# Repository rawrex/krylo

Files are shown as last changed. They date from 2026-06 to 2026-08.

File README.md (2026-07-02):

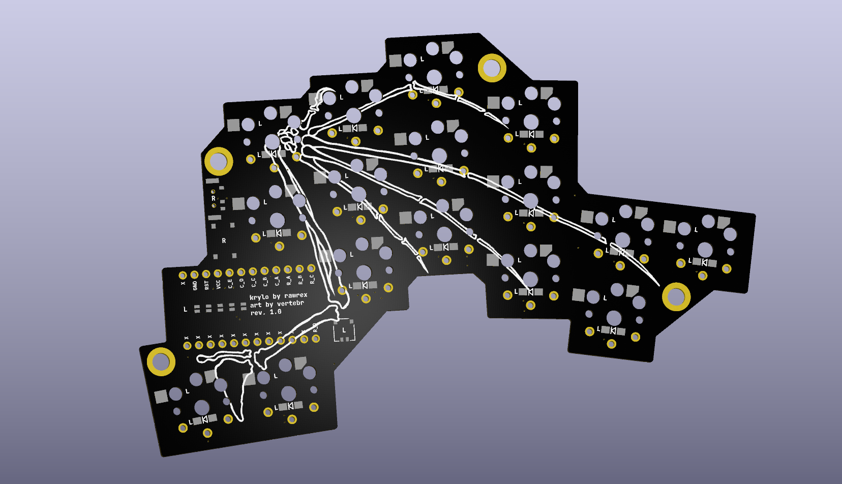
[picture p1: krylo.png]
krylo split keyboard


**Krylo** (*"wing"* in Russian) is a 32 key column-staggered split keyboard running [ZMK](https://zmk.dev/)

Core ideas that motivated the project:
- (My) pinky moves to the side better than it reaches forward to the upper row.
- (My) index finger is also able to move to the side, but it is not comfortable to move to the side and down.
- Single PCB symmetrical definition for both sides of the split.

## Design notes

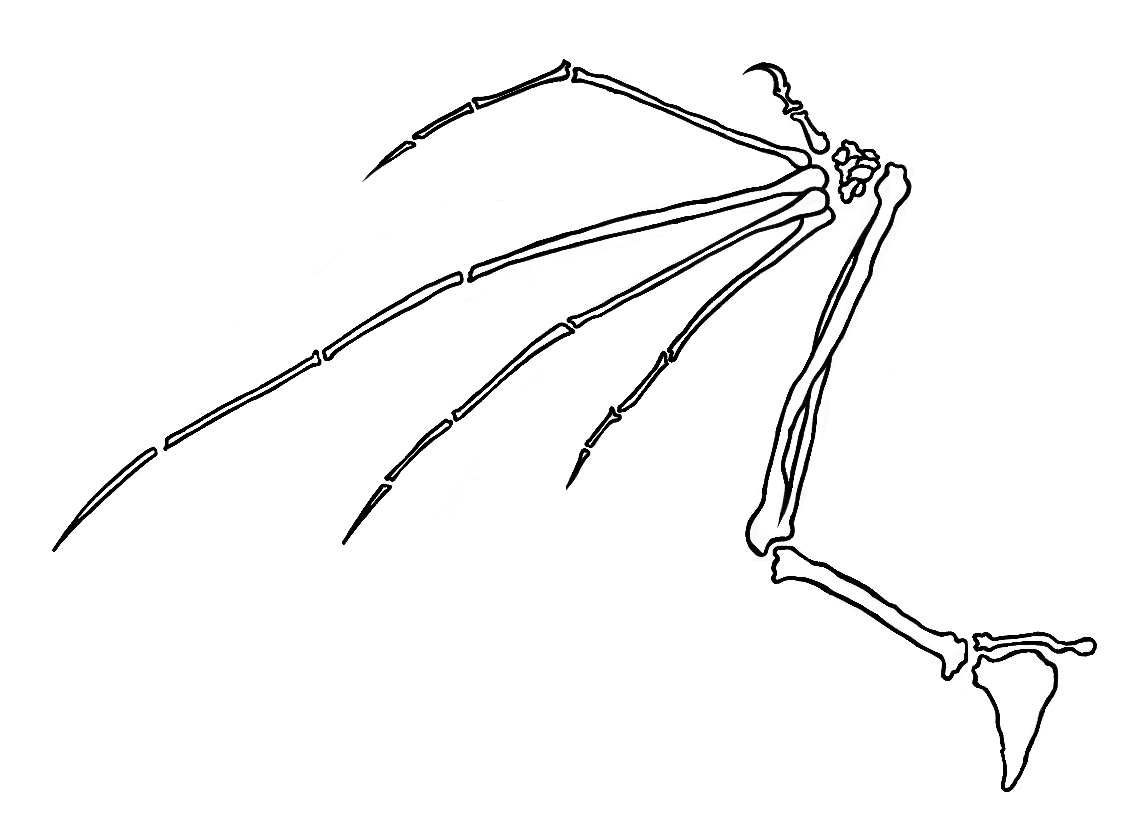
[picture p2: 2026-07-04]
PCB/krylo.png

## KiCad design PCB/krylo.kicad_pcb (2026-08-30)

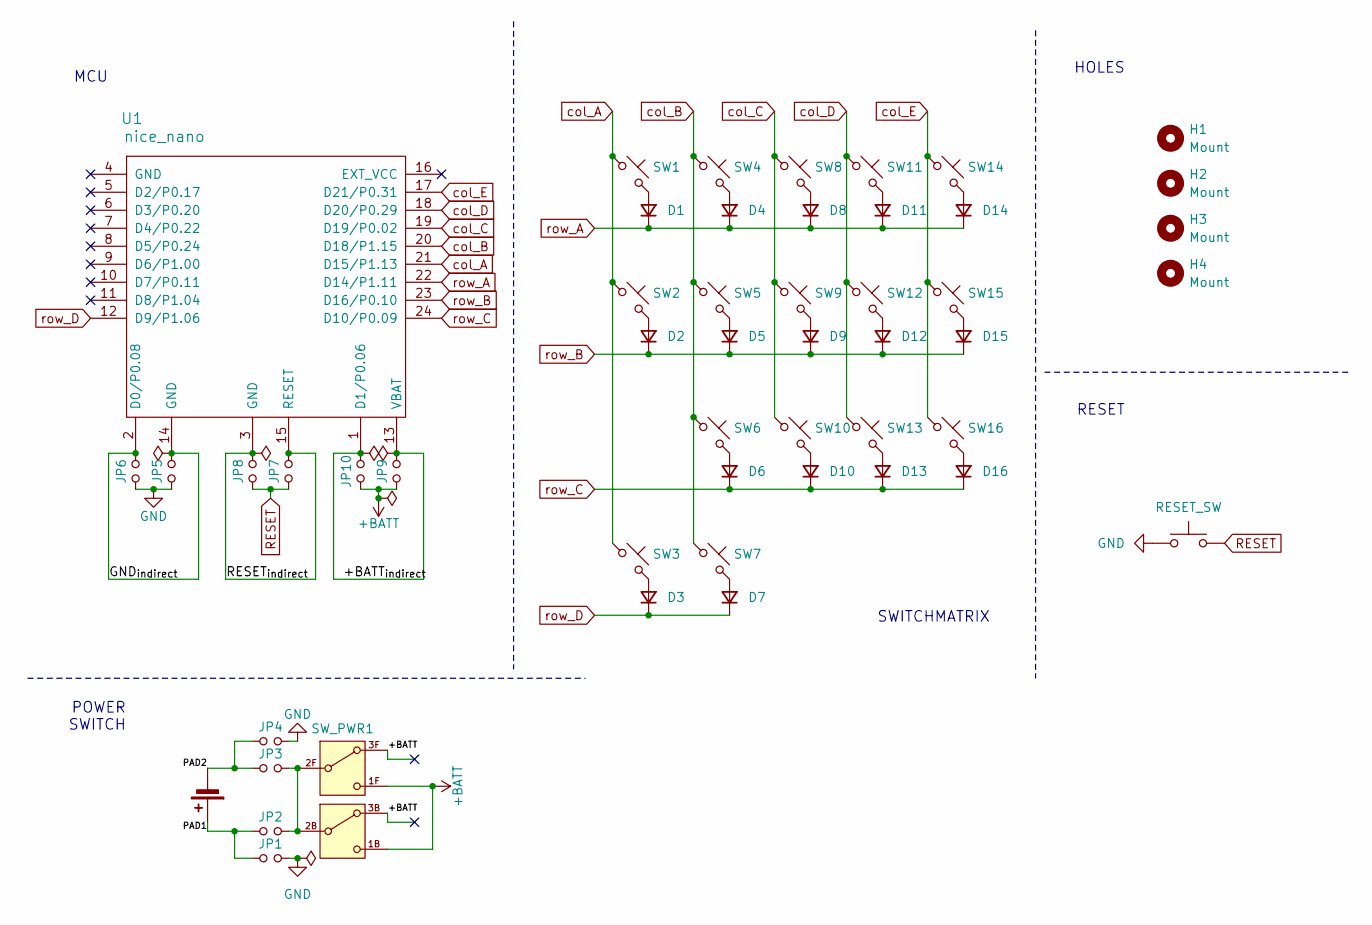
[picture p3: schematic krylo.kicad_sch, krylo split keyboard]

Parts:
BT1: MOLEX_C
D1, D2, D3, D4, D5, D6, D7, D8, D9, D10, D11, D12, D13, D14, D15, D16: D_SOD123
H1, H2, H3, H4: Mount
JP1, JP2, JP3, JP4, JP5, JP6, JP7, JP8, JP9, JP10: Jumper
RESET1: RESET_SW; ResetSW
SW1, SW2, SW3, SW4, SW5, SW6, SW7, SW8, SW9, SW10, SW11, SW12, SW13, SW14, SW15, SW16: Switch
SW_PWR1: MSK12C02
U1: nice_nano

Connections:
+BATT: JP9.1, JP10.1, SW_PWR1.1B (C_back), SW_PWR1.1F (C_front), SW_PWR1.3B (A_back), SW_PWR1.3F (A_front)
/+BATT_{indirect}: JP9.2, JP10.2, U1.1 (D1/P0.06), U1.13 (VBAT)
/GND_{indirect}: JP5.2, JP6.2, U1.2 (D0/P0.08), U1.14 (GND)
/PAD1: BT1.1 (+), JP1.1, JP2.1
/PAD2: BT1.2 (-), JP3.1, JP4.1
/RESET_{indirect}: JP7.2, JP8.2, U1.3 (GND), U1.15 (RESET)
GND: JP1.2, JP4.2, JP5.1, JP6.1, RESET1.1
unnamed: D1.2 (A), SW1.2
unnamed: D2.2 (A), SW2.2
unnamed: D3.2 (A), SW3.2
unnamed: D4.2 (A), SW4.2
unnamed: D5.2 (A), SW5.2
unnamed: D6.2 (A), SW6.2
unnamed: D7.2 (A), SW7.2
unnamed: D8.2 (A), SW8.2
unnamed: D9.2 (A), SW9.2
unnamed: D10.2 (A), SW10.2
unnamed: D11.2 (A), SW11.2
unnamed: D12.2 (A), SW12.2
unnamed: D13.2 (A), SW13.2
unnamed: D14.2 (A), SW14.2
unnamed: D15.2 (A), SW15.2
unnamed: D16.2 (A), SW16.2
unnamed: JP2.2, JP3.2, SW_PWR1.2B (B_back), SW_PWR1.2F (B_front)
RESET: JP7.1, JP8.1, RESET1.2
col_A: SW1.1, SW2.1, SW3.1, U1.21 (D15/P1.13)
col_B: SW4.1, SW5.1, SW6.1, SW7.1, U1.20 (D18/P1.15)
col_C: SW8.1, SW9.1, SW10.1, U1.19 (D19/P0.02)
col_D: SW11.1, SW12.1, SW13.1, U1.18 (D20/P0.29)
col_E: SW14.1, SW15.1, SW16.1, U1.17 (D21/P0.31)
row_A: D1.1 (K), D4.1 (K), D8.1 (K), D11.1 (K), D14.1 (K), U1.22 (D14/P1.11)
row_B: D2.1 (K), D5.1 (K), D9.1 (K), D12.1 (K), D15.1 (K), U1.23 (D16/P0.10)
row_C: D6.1 (K), D10.1 (K), D13.1 (K), D16.1 (K), U1.24 (D10/P0.09)
row_D: D3.1 (K), D7.1 (K), U1.12 (D9/P1.06)

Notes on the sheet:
SWITCHMATRIX
POWER SWITCH
HOLES
MCU
RESET

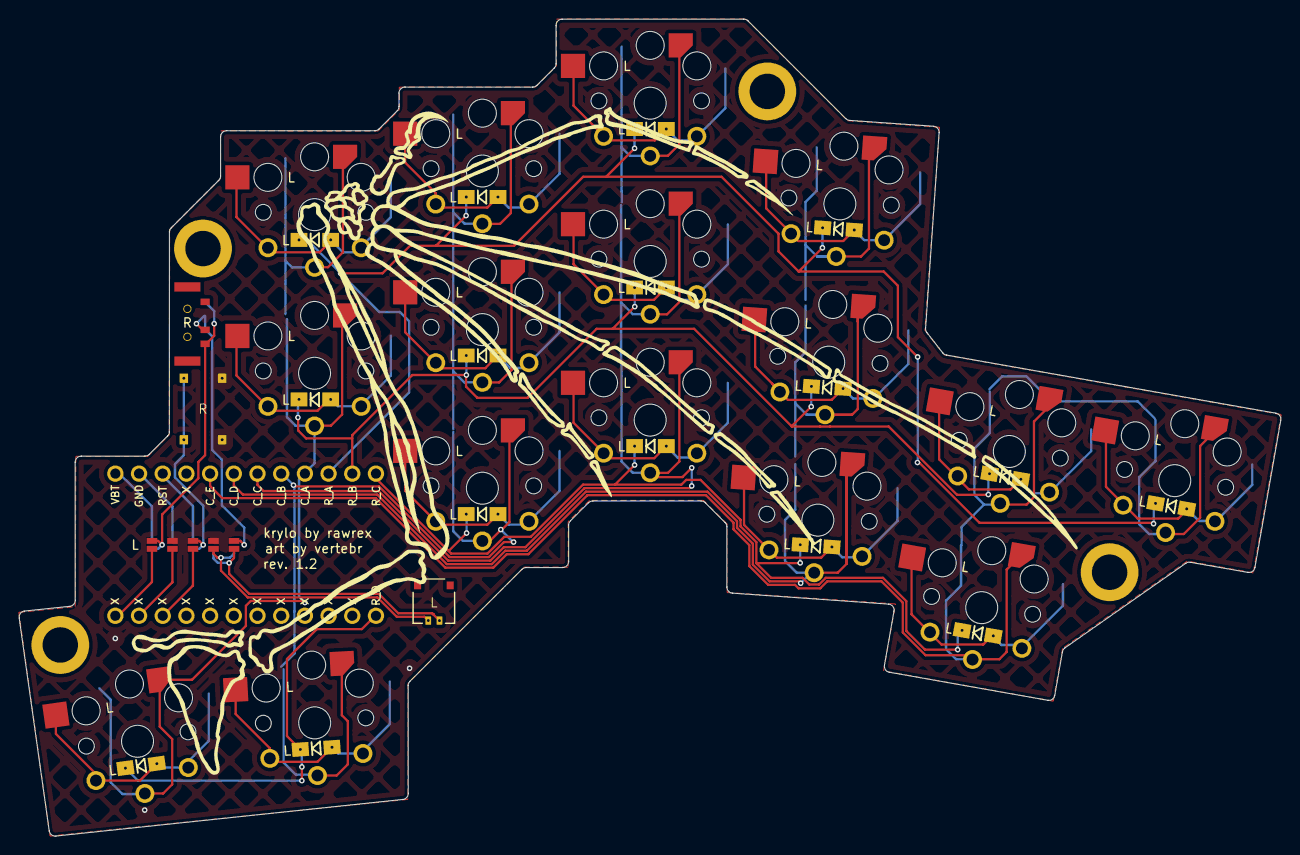
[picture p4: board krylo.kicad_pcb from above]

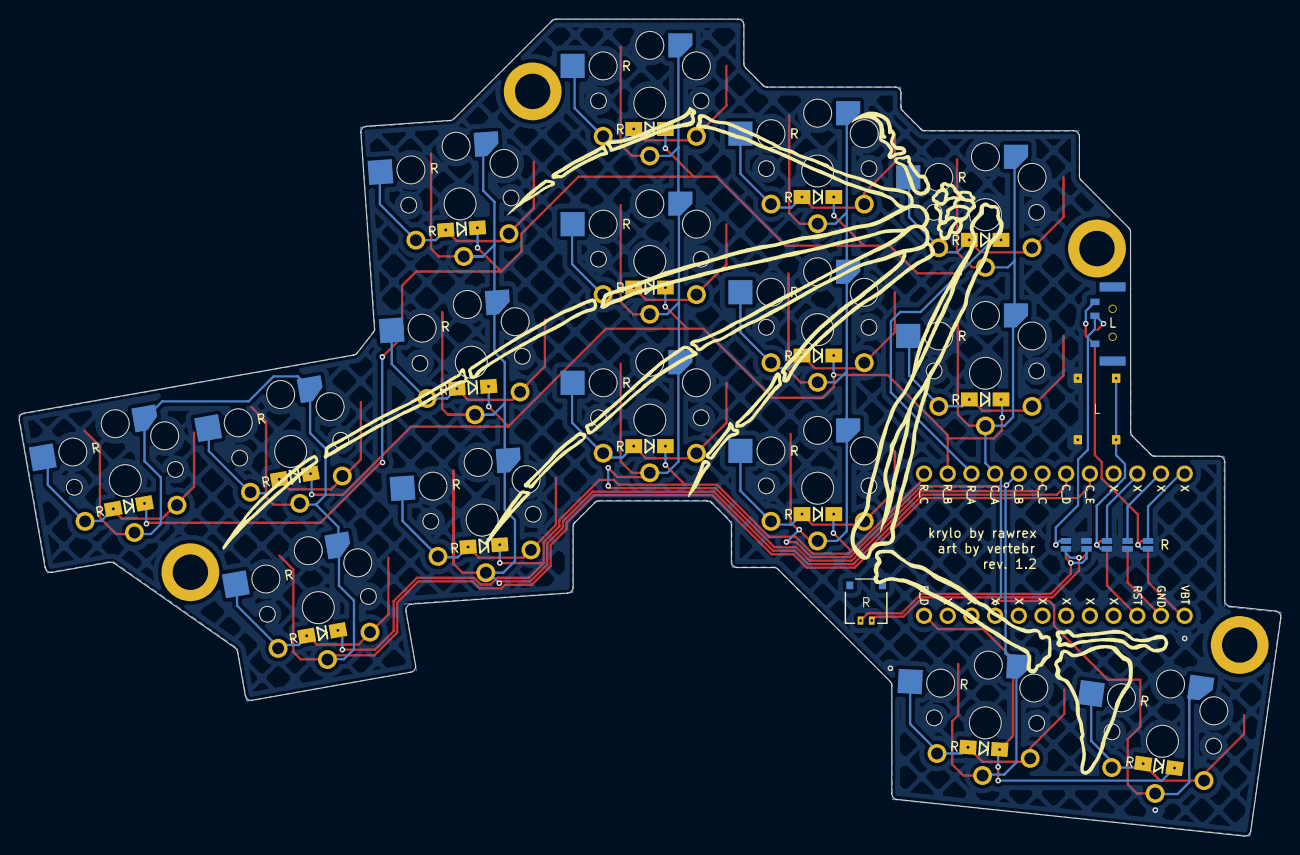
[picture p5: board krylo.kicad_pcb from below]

Board: 2 copper layers, 135.3 x 87.6 mm, 51 parts (5 on the bottom side), 34 nets.

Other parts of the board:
INFO: Info

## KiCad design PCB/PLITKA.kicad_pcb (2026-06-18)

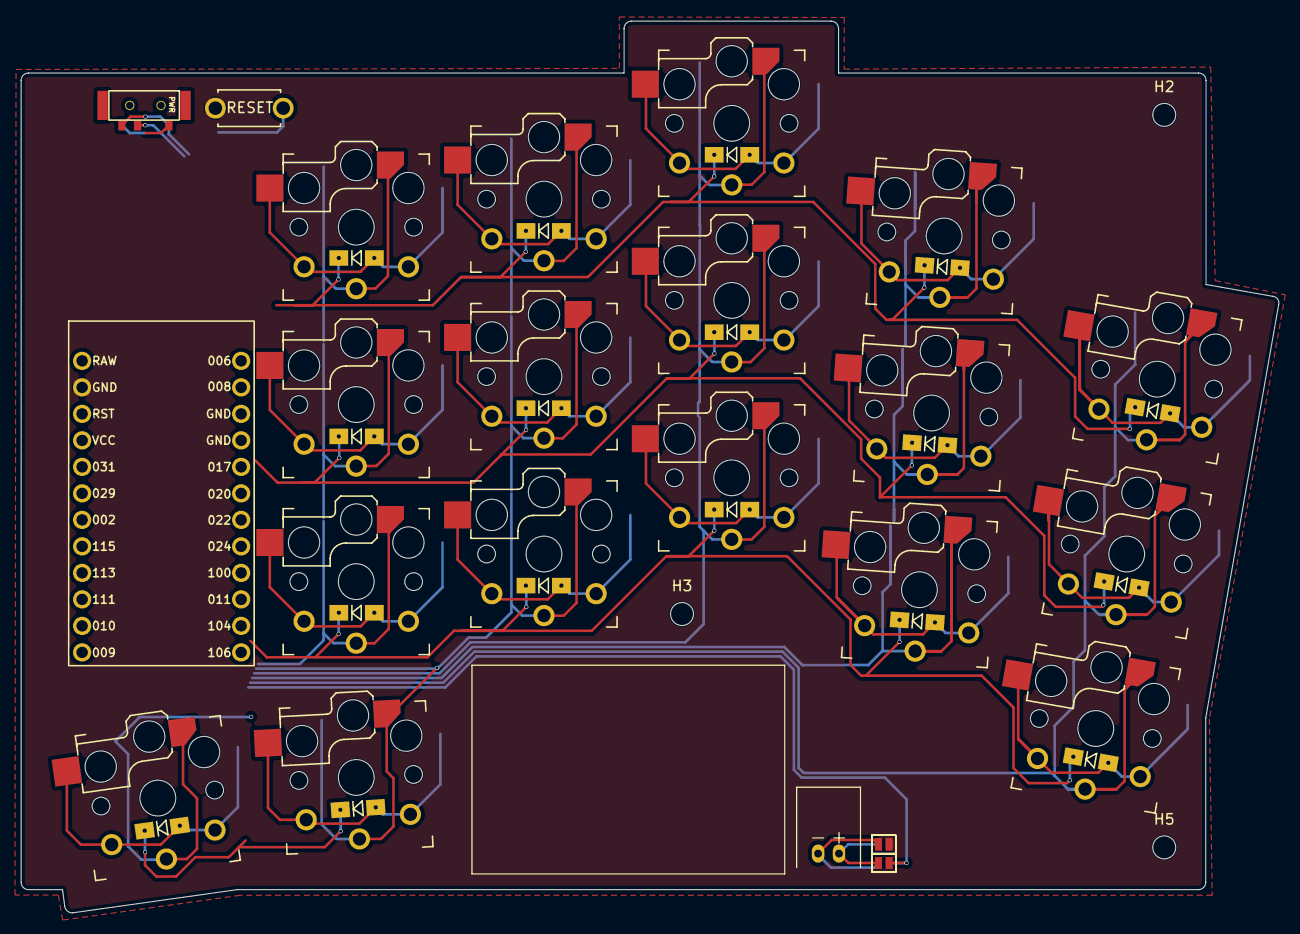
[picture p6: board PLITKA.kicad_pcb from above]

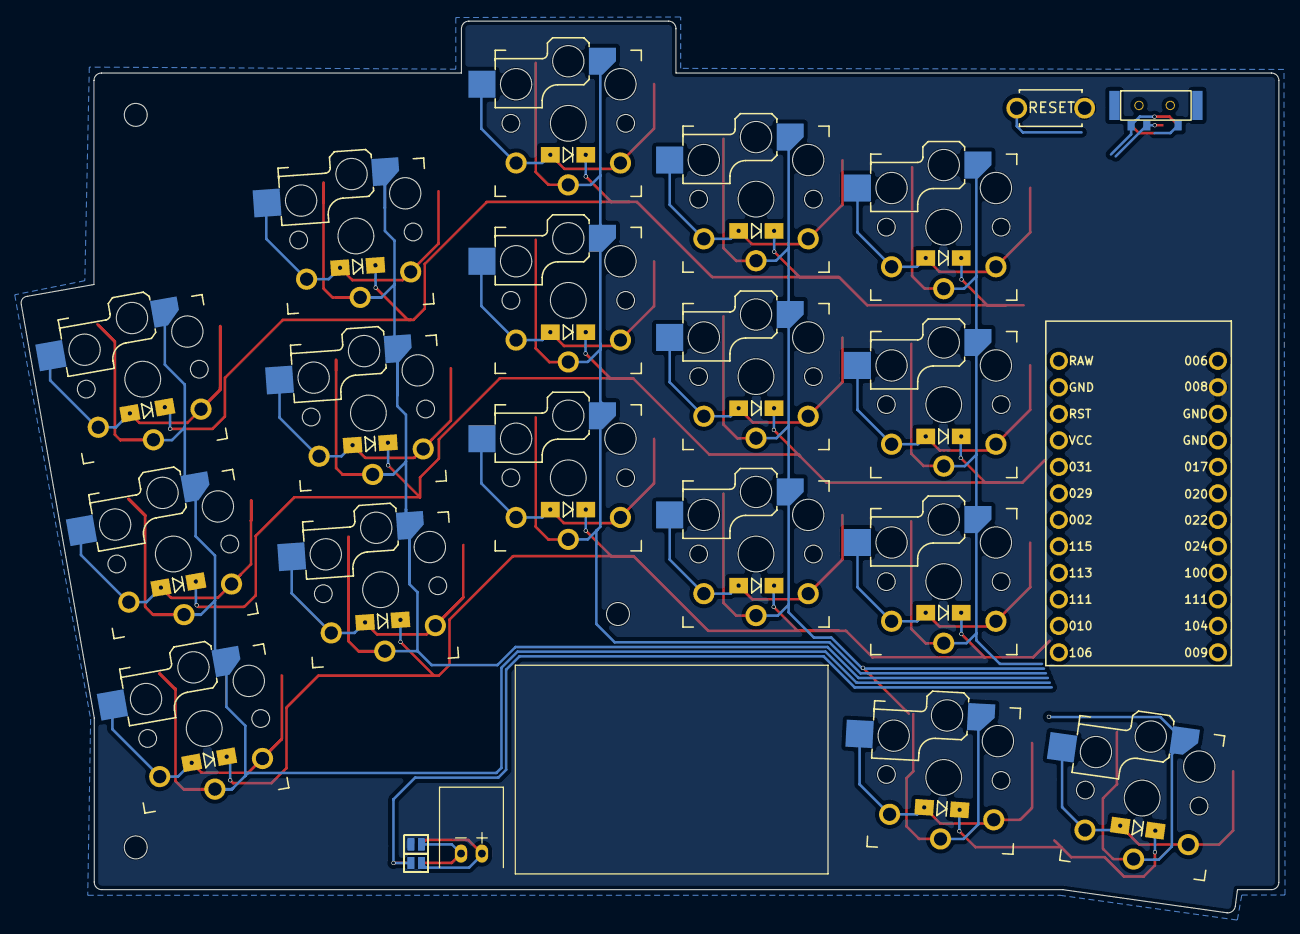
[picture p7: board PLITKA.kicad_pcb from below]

Board: 4 copper layers, 120.5 x 85.5 mm, 47 parts (2 on the bottom side), 32 nets.

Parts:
BT1: Battery_Cell; JST_PH_reversible
D1, D2, D3, D4, D5, D6, D7, D8, D9, D10, D11, D12, D13, D14, D15, D16, D17: D_Small; Diode_SOD123
H1, H2, H3, H4, H5: MountingHole; MountingHole_2.2mm_M2_ISO7380
JP1, JP2, JP3, JP4: Device_Jumper_NO_Small; Jumper
SW1: SW_SPDT_321; MSK12C02_reversible
SW2, SW3, SW4, SW5, SW6, SW7, SW8, SW9, SW10, SW11, SW12, SW13, SW14, SW15, SW16, SW17, SW18: MX_SW_HS; Kailh_socket_PG1350_optional_reversible
SW19: SW_Push; ResetSW
U1: nice!nano; nice_nano

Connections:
+BATT: SW1.3 (A), U1.16 (EXT_VCC)
/PAD1: BT1.1 (+), JP1.1, JP2.1
/PAD2: BT1.2 (-), JP3.1, JP4.1
GND: JP1.2, JP4.2, SW19.1, U1.14 (GND)
unnamed: D1.2 (A), SW2.2
unnamed: D2.2 (A), SW3.2
unnamed: D3.2 (A), SW4.2
unnamed: D4.2 (A), SW5.2
unnamed: D5.2 (A), SW6.2
unnamed: D6.2 (A), SW7.2
unnamed: D7.2 (A), SW8.2
unnamed: D8.2 (A), SW9.2
unnamed: D9.2 (A), SW10.2
unnamed: D10.2 (A), SW11.2
unnamed: D11.2 (A), SW12.2
unnamed: D12.2 (A), SW13.2
unnamed: D13.2 (A), SW14.2
unnamed: D14.2 (A), SW15.2
unnamed: D15.2 (A), SW16.2
unnamed: D16.2 (A), SW17.2
unnamed: D17.2 (A), SW18.2
unnamed: JP2.2, JP3.2, SW1.2 (B)
RESET: SW19.2, U1.15 (RESET)
col_A: SW2.1, SW3.1, SW4.1, SW5.1, U1.5 (D2/P0.17)
col_B: SW6.1, SW7.1, SW8.1, SW9.1, U1.6 (D3/P0.20)
col_C: SW10.1, SW11.1, SW12.1, U1.7 (D4/P0.22)
col_D: SW13.1, SW14.1, SW15.1, U1.8 (D5/P0.24)
col_E: SW16.1, SW17.1, SW18.1, U1.9 (D6/P1.00)
row_A: D1.1 (K), D5.1 (K), D9.1 (K), D12.1 (K), D15.1 (K), U1.10 (D7/P0.11)
row_B: D2.1 (K), D6.1 (K), D10.1 (K), D13.1 (K), D16.1 (K), U1.11 (D8/P1.04)
row_C: D3.1 (K), D7.1 (K), D11.1 (K), D14.1 (K), D17.1 (K), U1.12 (D9/P1.06)
row_D: D4.1 (K), D8.1 (K), U1.24 (D10/P0.09)

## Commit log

2026-06-12 No knub for the plitka
    [GEIST_EC12knob_v02_06.step, GEIST_EC12knob_v02_06.stl, KLOTZ_EC12-knob_v02_04.stl]
2026-06-12 Encoder connections are removed
    [PLITKA.kicad_sch]
2026-06-13 Non-JSC battery connection removed
    [PLITKA.kicad_pcb, PLITKA.kicad_sch]
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2026-06-17 Power flags errors correction
    [PLITKA.kicad_sch]
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2026-06-18 Minor cosmetic correction
    [PLITKA.kicad_sch]
2026-06-18 Set up the board settings from the JLC PCB template
    [PLITKA.kicad_pcb]
2026-06-19 Case correction
2026-06-19 Rudimentary files clean up
    [pinky.kicad_pcb]
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2026-06-20 Proper fill zones for the board
    [pinky.kicad_pcb]
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2026-06-22 Power and reset switches with explicit references
    [pinky.kicad_pcb, pinky.kicad_sch]
2026-06-23 Configuration jumpers for GPIO pins on the MCU
    [pinky.kicad_sch]
2026-06-26 Existing 3D models clean up and addition of the hot swap for the switch footprint
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2026-06-28 Routes configuration in process
    [pinky.kicad_pcb]
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2026-06-29 Board edge clearance violations fix
    [pinky.kicad_pcb]
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2026-06-29 Internalized the mounting hole footprint to clean it up and to remove the DRC warning
    [pinky.kicad_pcb, pinky.kicad_sch]
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2026-06-30 Fixed the silkscreen clipping warning
    [pinky.kicad_pcb]
2026-06-30 More tracks clean up
    [pinky.kicad_pcb]
2026-06-30 Explicit track to GND from the RESET pin
    [pinky.kicad_pcb]
2026-06-30 Filenames clean up for consistency
    [pinky.kicad_pcb]
2026-06-30 Rudimentary lines cleaned out of the symbol
    [pinky.kicad_sch]
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2026-07-01 Double sided PCB use of the controllers GPIO pins is now reflected in the schematic
    [krylo.kicad_pcb, krylo.kicad_sch]
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2026-07-02 Sync external symbol library descriptions with footprints
    - Update Description values in krylo.kicad_sym to match .kicad_mod files
    - Document field sync workflow in AGENTS.md
    - D_SOD123: 'Diode, small symbol' -> '1N4148W SMD diode'
    - JST_PH: 'Single-cell battery' -> 'JST PH 2-pin battery connector'
    - MSK12C02: 'Switch, single pole double throw' -> 'MSK12C02 SPDT slide switch'
    - MountingHole: 'Mounting Hole without connection' -> 'M2 mounting hole'
    - ResetSW: 'Push button switch, generic, two pins' -> 'Tactile reset button'
2026-07-02 Clean ups and syncs
    [krylo.kicad_pcb, krylo.kicad_sch]
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2026-07-02 Schematic is made so that it contains the double sided PCB configuration. The power component is now (conceptually) contains two switches and routes them accordingly.
    [krylo.kicad_pcb, krylo.kicad_sch]
2026-07-02 Clean up and refill
    [krylo.kicad_pcb]
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2026-07-02 Case fixes
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2026-07-02 Updated the incorrect paths to the model
    [krylo.kicad_pcb]
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2026-07-03 ERC exclusions added, all errors/warnings are due to the double-sided PCB
2026-07-03 More informative silkscreen labels for the pins for the MCU, with correction of the 3D model placement
2026-07-03 MCU placement face correction
    [krylo.kicad_pcb]
2026-07-03 Fix: correction of the MCU top/bottom pin usage and placement as well as silkscreen corrections
    [krylo.kicad_pcb, krylo.kicad_sch]
2026-07-03 DRC error corrected, clearance
    [krylo.kicad_pcb]
2026-07-04 Added an artwork of a wing of a bat to the pcb
    [krylo.kicad_pcb]
2026-07-04 Diodes side hint added
    [krylo.kicad_pcb]
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2026-07-04 Power switch side hints added
    [krylo.kicad_pcb]
2026-07-04 Added side hint for the reset button
    [krylo.kicad_pcb]
2026-07-04 MCU side placement hind added
    [krylo.kicad_pcb]
2026-07-04 MCU silkscreen text alignment
    [krylo.kicad_pcb]
2026-07-04 Side hints for the jumpers
    [krylo.kicad_pcb]
2026-07-04 MCU courtyard added, silkscreen removed
    [krylo.kicad_pcb]
2026-07-04 Removed all non-functional or non-informative silkscreen prints
    [krylo.kicad_pcb]
2026-07-04 Side hint for the switch hot swaps
    [krylo.kicad_pcb]
2026-07-04 Cleared side hint for the MCU
    [krylo.kicad_pcb]
2026-07-04 JST_PH footprint update to reflect the actual component at hand
    [krylo.kicad_pcb]
2026-07-05 Font updated to NerdBrains
    [krylo.kicad_pcb]
2026-07-05 Jumper reference numbers are sorted
    [krylo.kicad_pcb, krylo.kicad_sch]
2026-07-05 Jumpers now configure the opposite side. We solder jumpers on the bottom of each side of the split
    [krylo.kicad_pcb, krylo.kicad_sch]
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2026-07-05 Configuration of the JST connector is also done for on the bottom side of the PCB
    [krylo.kicad_pcb, krylo.kicad_sch]
2026-07-05 Side hints for the jumpers are updated, the font is updated as well
    [krylo.kicad_pcb]
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2026-07-05 Full updates pull and tracks clean up
    [krylo.kicad_pcb]
2026-07-05 Silkscreen moved out from the pads
    [krylo.kicad_pcb]
2026-07-05 Another silkscreen clearance measure
    [krylo.kicad_pcb]
2026-07-06 Mirrored sign on the backside
    [krylo.kicad_pcb]
2026-07-06 Fix: Edge cut connection
    [krylo.kicad_pcb]
2026-07-06 A stitching via added
    [krylo.kicad_pcb]
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2026-07-06 Typeface issue resolvement
    [krylo.kicad_pcb]
2026-07-06 Bolder font for all
    [krylo.kicad_pcb]
2026-07-06 Text mirrored at the footprint (finally)
    [krylo.kicad_pcb]
2026-07-06 DRC silkscreen warnings are ignored now
    [krylo.kicad_pcb]
2026-07-06 The mounting solution is changed to the solderable M2 nuts. Work in progress
    [krylo.kicad_pcb, krylo.kicad_sch]
2026-07-07 Added fifth mount point and edited the edges to contain the updated mounts
    [krylo.kicad_pcb, krylo.kicad_sch]
2026-07-07 Added 3D model for the SMT_M2 footprint
    [krylo.kicad_pcb]
2026-07-07 Added a molex connector in place of the jst one
    [krylo.kicad_pcb, krylo.kicad_sch]
2026-07-07 JST replaced by Molex, symbols correction and update for the smt_m2 and molex
    [krylo.kicad_pcb, krylo.kicad_sch]
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2026-07-07 Refill, updates pull, tracks clean up
    [krylo.kicad_pcb]
2026-07-07 Mount points repositioned. Edge cuts revisioned, starting to position the Molex_connector
    [krylo.kicad_pcb, krylo.kicad_sch]
2026-07-07 Molex footprint side hint, 3D model placement correction. Zone fill
    [krylo.kicad_pcb]
2026-07-07 Power connector double-side use routing configuration done
    [krylo.kicad_pcb]
2026-07-08 Updates pull, refill, tracks clean up
    [krylo.kicad_pcb]
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2026-07-08 Clean up and rules update
    [krylo.kicad_pcb]
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2026-07-08 Removed unused footprint and consequential update pulls done
    [krylo.kicad_pcb, krylo.kicad_sch]
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2026-07-09 Reset button changed to a more compact one
    [krylo.kicad_pcb, krylo.kicad_sch]
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2026-07-09 Silkscreen side hint added to the reset button
    [krylo.kicad_pcb]
2026-07-09 Battery connector silkscreen orientation correction
    [krylo.kicad_pcb]
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2026-07-09 Repositioned the reset button and the mount point to make them a bit more centered relative to the resulting area
    [krylo.kicad_pcb]
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2026-07-10 Jumpers placement correction
    [krylo.kicad_pcb, krylo.kicad_sch]
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2026-07-10 Revert "Image update after board edits"
    This reverts commit fc8fca6fc856697f6b5c37f1d0712afe283670be.
2026-08-16 Fix: added the missing connection of the left backside power jumper
    [krylo.kicad_pcb]
2026-08-29 Fix: power goes to the VBAT pin instead of the EXT_GCC, this way we fix the inability to read the battery values by the MCU and avoid the soft off charge drain issue
    [krylo.kicad_pcb, krylo.kicad_sch]
2026-08-30 Jumper pads narrowed down and track clean up
    [krylo.kicad_pcb]
2026-08-30 Clean ups and alignments after the jumpers narrowing and moving
    [krylo.kicad_pcb]
2026-08-30 MCU labels correction after the VBAT/VCC fix
    [krylo.kicad_pcb]
2026-08-30 A full area fill with more narrower grid
    [krylo.kicad_pcb]
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
